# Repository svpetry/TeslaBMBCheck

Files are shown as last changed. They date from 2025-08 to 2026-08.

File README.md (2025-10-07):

# TeslaBMBCheck
Simple device that reads the voltage levels and temperatures from a Tesla Model S BMB board. It also supports balancing and clearing faults.

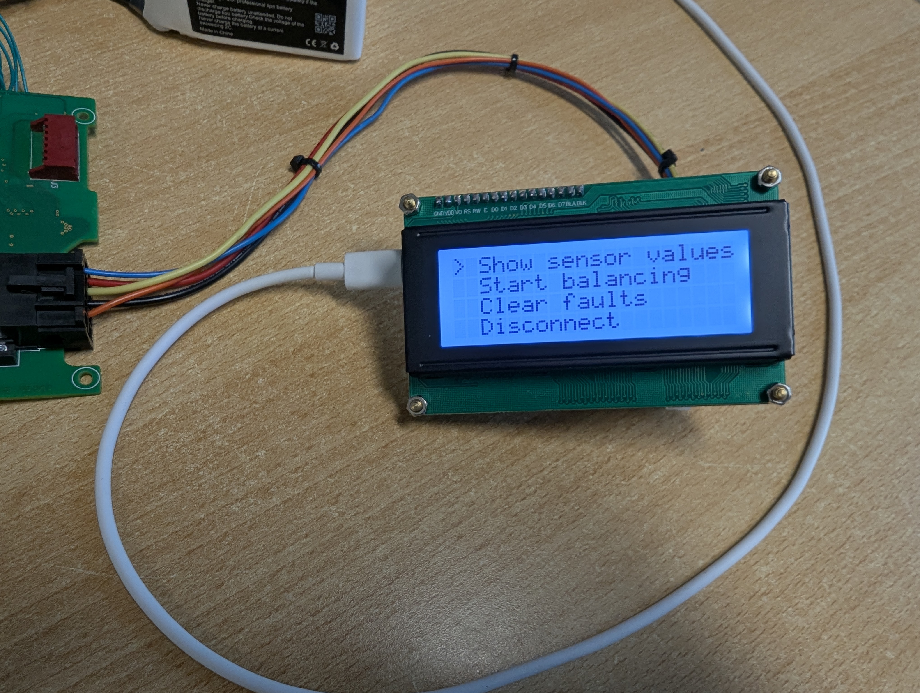
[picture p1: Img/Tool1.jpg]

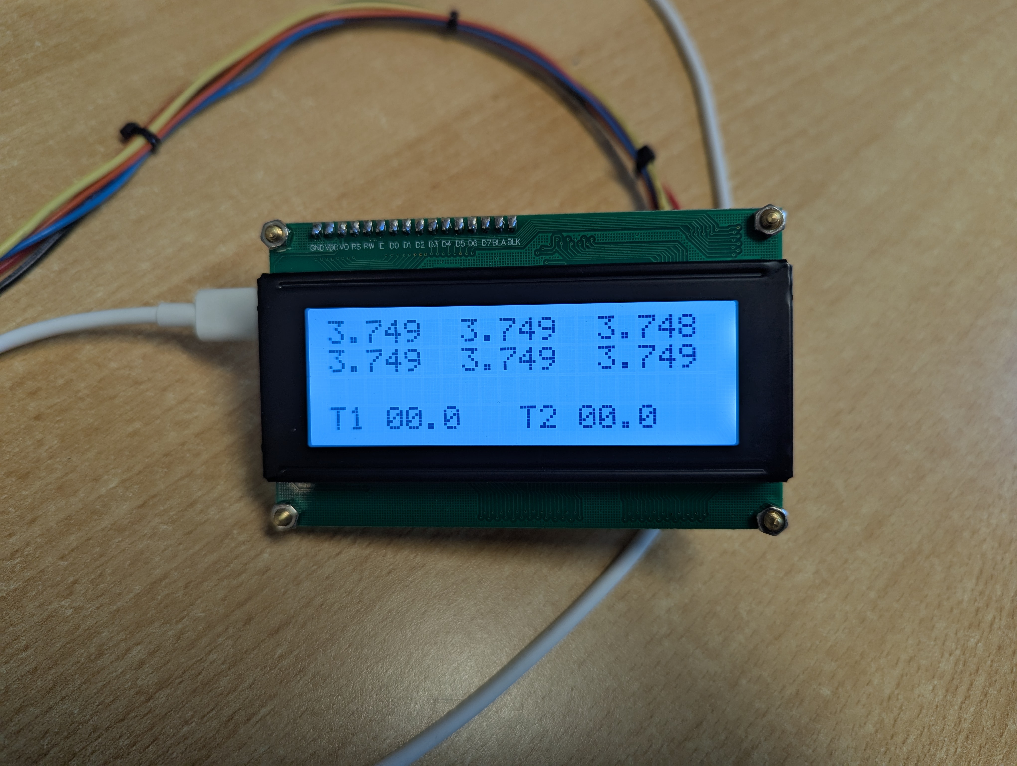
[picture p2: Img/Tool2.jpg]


## Module Locations

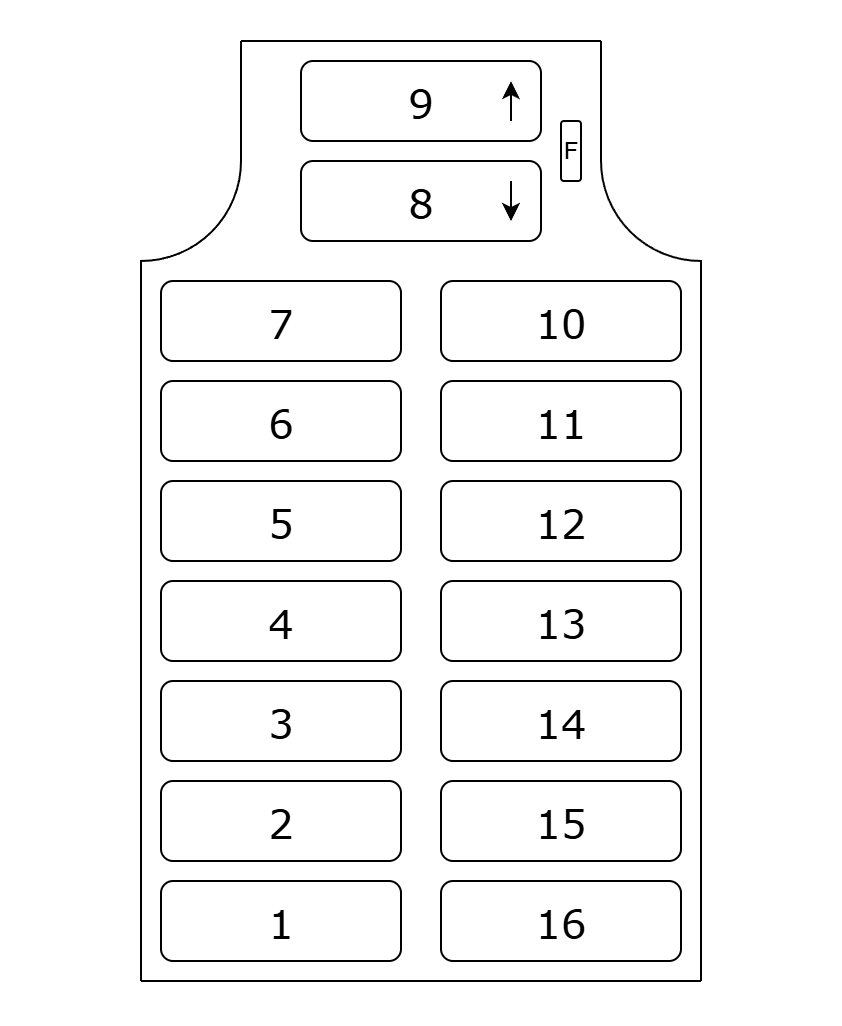
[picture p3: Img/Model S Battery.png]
Model S Battery Modules


## BMB Components

For each brick the BMB has a group of identical SMD components to read the voltage levels and do balancing. The elements in the topmost rectangle have already been replaced and re-sealed with epoxy.

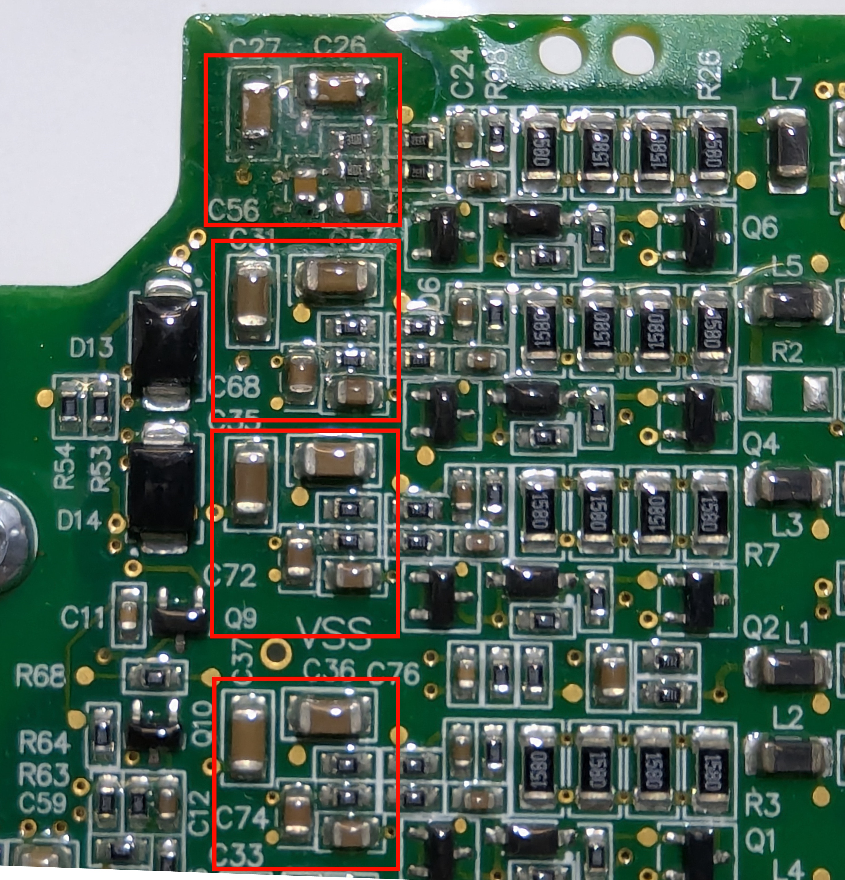
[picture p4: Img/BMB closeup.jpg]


## BMB Single Group For A Brick

The components here often have corrosion damage.

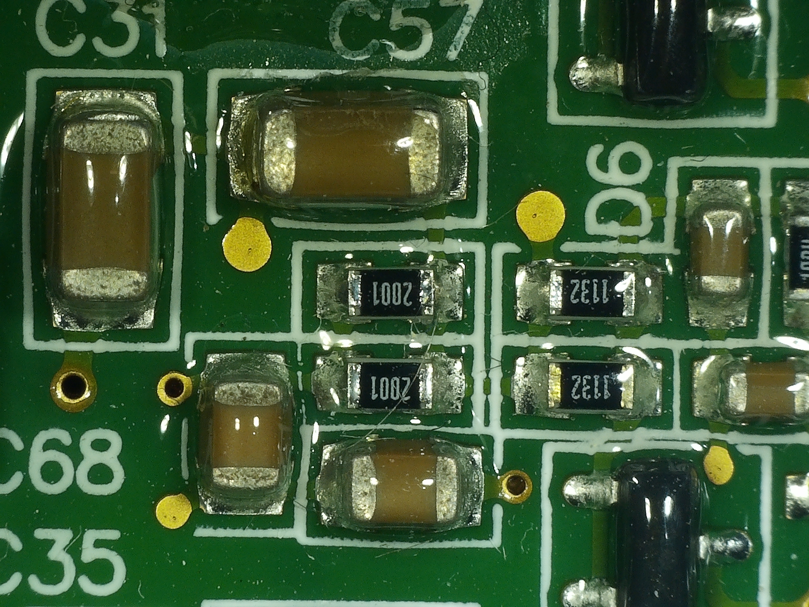
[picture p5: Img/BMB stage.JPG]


## BMB Resistor And Capacitor Values

These are the values I measured.

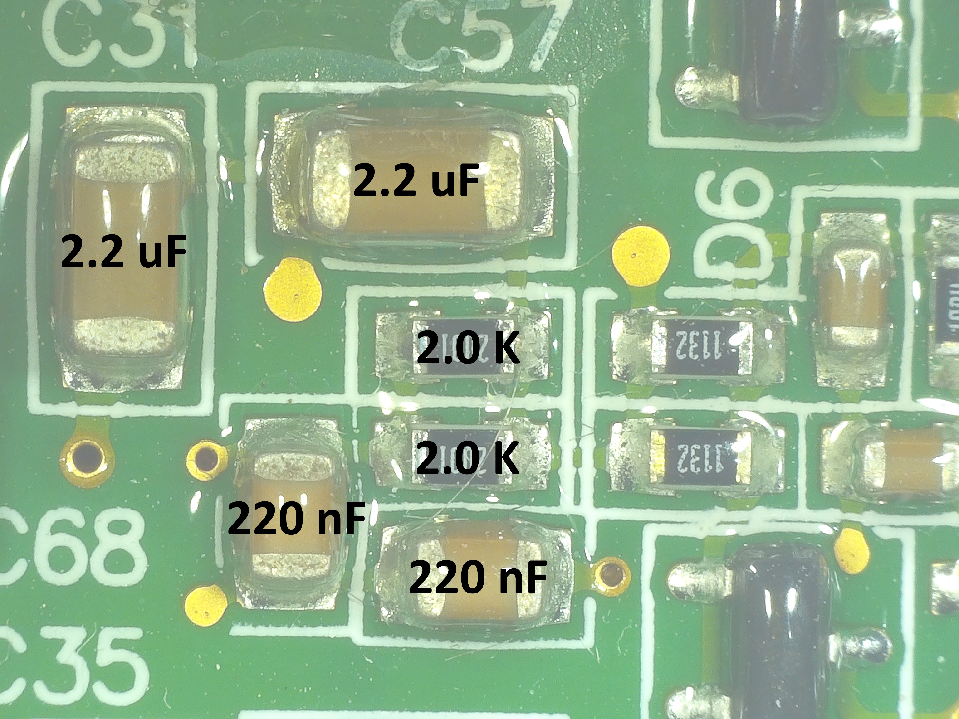
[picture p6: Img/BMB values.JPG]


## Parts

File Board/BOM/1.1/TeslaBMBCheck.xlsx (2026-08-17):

Name | Qty | Value
C1,C3,C4 | 3 | 100n
C2,C7 | 2 | 10u
C5 | 1 | 1u
C6 | 1 | 47n
C15,C17 | 2 | 22p
D2 | 1 | SS14
D15 | 1 | INFO
DS1 | 1 | WC1602A
J1 | 1 | TESLA_BMS
J2 | 1 | CHARGE
J9 | 1 | ICSP
K2 | 1 | SLA-05VDC-SL-C
Q1 | 1 | IRLML2244
Q2 | 1 | BSS138
Q3 | 1 | IRLML2502
R1,R2 | 2 | 5K1
R3,R4,R5 | 3 | 4K7
R6 | 1 | 15
R7,R8,R23 | 3 | 10K
R10 | 1 | 15K
R19 | 1 | 1K
RV1 | 1 | 10K
SW1,SW2 | 2
U1 | 1 | USBLC6
U2 | 1 | PIC18F2480-ISO
USB1 | 1 | POWER
Y1 | 1 | 10 MHz

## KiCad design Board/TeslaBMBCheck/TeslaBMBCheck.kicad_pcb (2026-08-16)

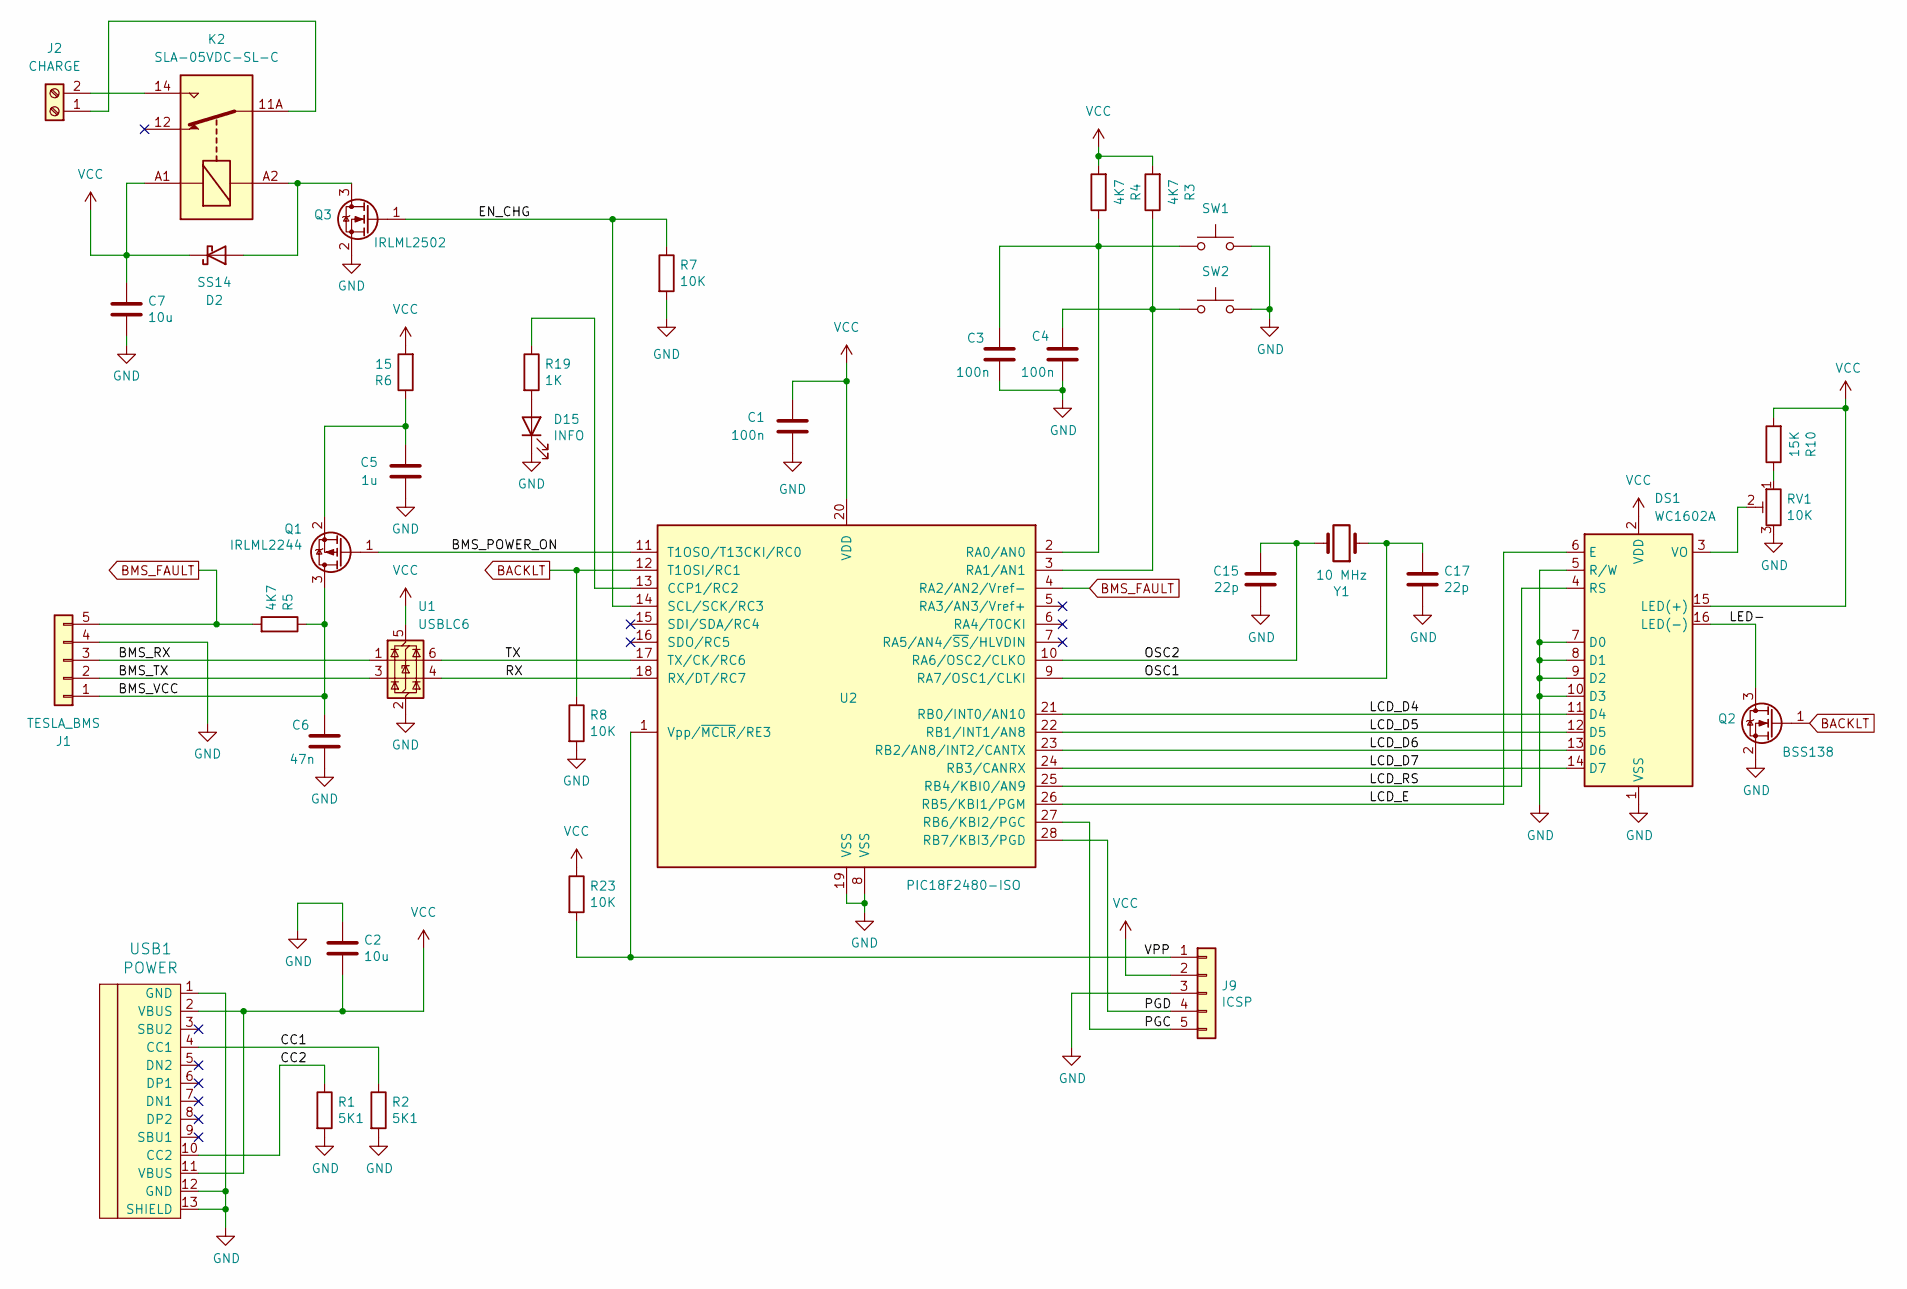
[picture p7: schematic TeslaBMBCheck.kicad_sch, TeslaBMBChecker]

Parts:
C1, C3, C4: 100n; C_0805_2012Metric
C2, C7: 10u; C_1206_3216Metric
C5: 1u; C_0805_2012Metric
C6: 47n; C_0805_2012Metric
C15, C17: 22p; C_0805_2012Metric
D2: SS14; D_SMA
D15: INFO; LED_0805_2012Metric
DS1: WC1602A; LCD-20x4
J1: TESLA_BMS; Molex_Mini-Fit_Jr_5566-10A_1x05_P4.20mm_Vertical
J2: CHARGE; KF7.62_2P
J9: ICSP; PinHeader_1x05_P2.54mm_Vertical
K2: SLA-05VDC-SL-C; Relay_SPDT_RAYEX-L90
Q1: IRLML2244; SOT-23
Q2: BSS138; SOT-23
Q3: IRLML2502; SOT-23
R1, R2: 5K1; R_0805_2012Metric
R3, R4, R5: 4K7; R_0805_2012Metric
R6: 15; R_0805_2012Metric
R7, R8, R23: 10K; R_0805_2012Metric
R10: 15K; R_0805_2012Metric
R19: 1K; R_0805_2012Metric
RV1: 10K; Potentiometer_Bourns_TC33X_Vertical
SW1, SW2: SW_SPST_CK_RS282G05A3
U1: USBLC6; SOT-23-6
U2: PIC18F2480-ISO; SOIC-28W_7.5x17.9mm_P1.27mm
USB1: POWER; HRO-TYPE-C-31-M-12
Y1: 10 MHz; Crystal_SMD_HC49-SD

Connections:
/BMS_POWER_ON: Q1.1 (G), U2.11 (T1OSO/T13CKI/RC0)
/BMS_RX: J1.3, U1.1 (I/O1)
/BMS_TX: J1.2, U1.3 (I/O2)
/BMS_VCC: C6.1, J1.1, Q1.3 (D), R5.1
/CC1: R2.1, USB1.4 (CC1)
/CC2: R1.1, USB1.10 (CC2)
/EN_CHG: Q3.1 (G), R7.1, U2.14 (SCL/SCK/RC3)
/LCD_D4: DS1.11 (D4), U2.21 (RB0/INT0/AN10)
/LCD_D5: DS1.12 (D5), U2.22 (RB1/INT1/AN8)
/LCD_D6: DS1.13 (D6), U2.23 (RB2/AN8/INT2/CANTX)
/LCD_D7: DS1.14 (D7), U2.24 (RB3/CANRX)
/LCD_E: DS1.6 (E), U2.26 (RB5/KBI1/PGM)
/LCD_RS: DS1.4 (RS), U2.25 (RB4/KBI0/AN9)
/LED-: DS1.16 (LED(-)), Q2.3 (D)
/OSC1: C17.1, U2.9 (RA7/OSC1/CLKI), Y1.1
/OSC2: C15.1, U2.10 (RA6/OSC2/CLKO), Y1.2
/PGC: J9.5, U2.27 (RB6/KBI2/PGC)
/PGD: J9.4, U2.28 (RB7/KBI3/PGD)
/RX: U1.4 (I/O2), U2.18 (RX/DT/RC7)
/TX: U1.6 (I/O1), U2.17 (TX/CK/RC6)
/VPP: J9.1, R23.2, U2.1 (Vpp/~MCLR/RE3)
BACKLT: Q2.1 (G), R8.1, U2.12 (T1OSI/RC1)
BMS_FAULT: J1.5, R5.2, U2.4 (RA2/AN2/Vref-)
GND: C1.2, C2.1, C3.2, C4.2, C5.2, C6.2, C7.2, C15.2, C17.2, D15.1 (K), DS1.1 (VSS), DS1.5 (R/W), DS1.7 (D0), DS1.8 (D1), DS1.9 (D2), DS1.10 (D3), J1.4, J9.3, Q2.2 (S), Q3.2 (S), R1.2, R2.2, R7.2, R8.2, RV1.3, SW1.2, SW2.2, U1.2 (GND), U2.8 (VSS), U2.19 (VSS), USB1.1 (GND), USB1.12 (GND), USB1.13 (SHIELD)
unnamed: D2.2 (A), K2.A2, Q3.3 (D)
unnamed: D15.2 (A), R19.2
unnamed: DS1.3 (VO), RV1.2
unnamed: J2.1, K2.11A, K2.11B
unnamed: J2.2, K2.14
unnamed: C5.1, Q1.2 (S), R6.1
unnamed: R10.1, RV1.1
unnamed: R19.1, U2.13 (CCP1/RC2)
unnamed: C3.1, R4.1, SW1.1, U2.2 (RA0/AN0)
unnamed: C4.1, R3.1, SW2.1, U2.3 (RA1/AN1)
VCC: C1.1, C2.2, C7.1, D2.1 (K), DS1.2 (VDD), DS1.15 (LED(+)), J9.2, K2.A1, R3.2, R4.2, R6.2, R10.2, R23.1, U1.5 (VBUS), U2.20 (VDD), USB1.2 (VBUS), USB1.11 (VBUS)

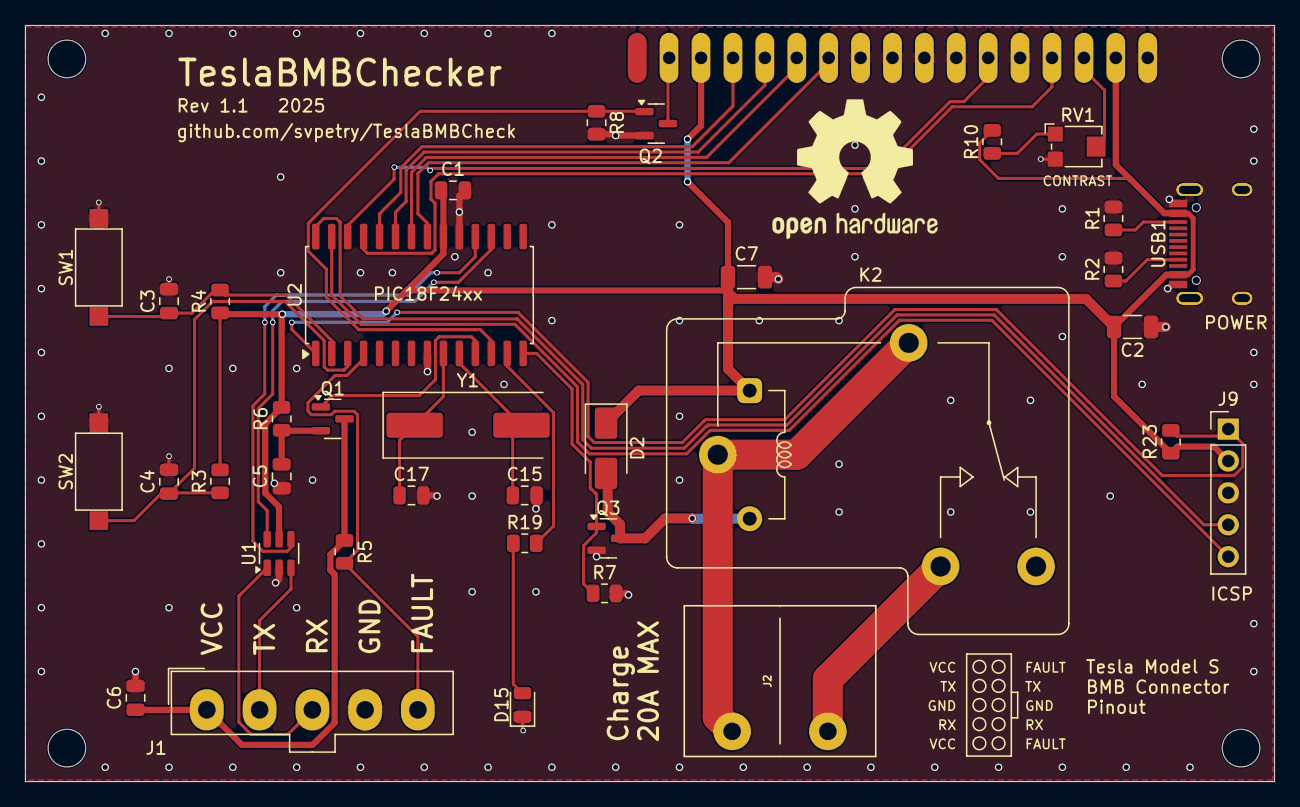
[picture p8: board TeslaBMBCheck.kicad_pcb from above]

Board: 2 copper layers, 99.4 x 60.2 mm, 37 parts (1 on the bottom side), 35 nets.

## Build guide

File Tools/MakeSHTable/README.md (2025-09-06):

This project is for generating the lookup table for the temperature calculation. I didn't want to include the float library into the PIC project, so everything is done with integer calculations.

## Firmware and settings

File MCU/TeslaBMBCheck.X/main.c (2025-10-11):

/*
 * File:   main.c
 * Author: svpet
 *
 * 
 * pin layout:
 * RA0: SW1 (0 = pressed)
 * RA1: SW2 (0 = pressed)
 * RA2: BMS_FAULT
 * RA3: -
 * RA4: -
 * RA5: -
 * RA6: OSC2
 * RA7: OSC1
 * RC0: BMS_POWER_ON (0 = active)
 * RC1: LCD backlight
 * RC2: Info LED
 * RC3: Charging relais
 * RC4: -
 * RC5: -
 * RC6: TX
 * RC7: RX
 * RE3: VPP (ICSP)
 * RB0: LCD_D4
 * RB1: LCD_D5
 * RB2: LCD_D6
 * RB3: LCD_D7
 * RB4: LCD_RS
 * RB5: LCD_E
 * RB6: PGC (ICSP)
 * RB7: PGD (ICSP)
 */

#include <xc.h>
#include <pic18f2480.h>
#include <string.h>
#include "config.h"
#include "base.h"
#include "lcd.h"
#include "uart.h"
#include "utils.h"
#include "bms-util.h"
#include "bms.h"
#include "board.h"
#include "types.h"

#define ENABLE_CHARGING 0

#define MODULE_ID 3
#define BMS_POWER_ON_DELAY 3000
#define BATT_SYMBOL_COUNT 4
#define VOLTAGE_CHECK_INTERVAL 5
#define CHARGE_CHECK_INTERVAL 60
#define MIN_CELL_VOLTAGE 2800
#define MAX_CELL_VOLTAGE 4175

bool connected = 0;

void Initialize(void) {
    TRISA = 0b11000111;
    LATA = 0;
    TRISB = 0b00000000;
    LATB = 0;
    TRISC = 0b10000000;
    LATC = 0b00000001;
    
    UART_Init(612500UL);

    __delay_ms(200);
    LcdInit();
}

void ConnectToBms(uint8_t module_id) {
    LcdClear();
    LcdPuts(4, 1, "Connecting...");
    
    connected = 0;
    
    SetBmsPower(1);
    __delay_ms(BMS_POWER_ON_DELAY);
    
    if (!ResetBoard()) {
        SetBmsPower(0);
        return;
    }
    if (!SetNewBoardId(module_id)) {
        SetBmsPower(0);
        return;
    }
    if (FindBoardId() != module_id) {
        SetBmsPower(0);
        return;
    }

    __delay_ms(100);
    ClearBmsFaults(MODULE_ID);

    connected = 1;
}

void DisconnectBms() {
    SetBmsPower(0);
    connected = 0;
    LcdClear();
    LcdPuts(4, 1, "Disconnected.");
    __delay_ms(1000);
}

void ShowBmsData(struct BmsData bms_data, bool show_temp) {
    char s[8];
    
    for (uint8_t cell = 0; cell < CELL_COUNT; cell++) {
        VoltageToStr(s, bms_data.v[cell], 0);
        LcdPuts((cell % 3) * 7, cell / 3, s);
    }
    
    if (show_temp) {
        for (uint8_t i = 0; i < 2; i++) {
            TempToStr(s, bms_data.t[i]);
            LcdPuts(3 + i * 10, 3, s);
        }
    } else {
        VoltageToStr(s, bms_data.mv, 1);
        LcdPuts(1, 3, s);
    }

    if (BmsFaultActive())
        LcdPuts(0, 2, "\x05\x06 Fault detected.");
    else
        LcdPuts(0, 2, "                    ");
}

void ShowStatus() {
    LcdClear();
    LcdPuts(0, 3, "T1");
    LcdPuts(10, 3, "T2");
    while (!GetBtnState(0) && !GetBtnState(1)) {
        struct BmsData data = ReadBmsData(MODULE_ID);
        ShowBmsData(data, 1);
        __delay_ms(1000);
    }
}

void ShowBatterySymbol(uint8_t cell, uint8_t counter, bool state) {
    uint8_t col = (cell % 3) * 7 + 5;
    uint8_t row = cell / 3;
    
    // Battery symbols are characters 1 (full), 2, 3 and 4 (empty)
    char battChar = 1 + counter;
    
    LcdPutChar(col, row, state ? battChar : ' ');
}

void EnableBalancers(bool balancers[CELL_COUNT]) {
    uint8_t bits = 0;
    for (int i = 0; i < CELL_COUNT; i++) {
        if (balancers[i])
            bits |= 1 << i;
    }
    EnableBmsBalancers(MODULE_ID, bits);
}

void Balance(uint16_t voltage) {
    LcdClear();

    bool balancers[CELL_COUNT];
    uint8_t batt_symbol = 0;
    
    char s[8];
    VoltageToStr(s, voltage, 0);
    LcdPuts(14, 3, s);
    
    struct BmsData data = ReadBmsData(MODULE_ID);
    ShowBmsData(data, 0);

    for (uint8_t cell = 0; cell < CELL_COUNT; cell++) {
        if (data.v[cell] > voltage) {
            ShowBatterySymbol(cell, batt_symbol, 1);
            balancers[cell] = 1;
        } else
            balancers[cell] = 0;
    }
    
    EnableBalancers(balancers);
    
    int seconds = 0;
    
    while (!GetBtnState(0) && !GetBtnState(1)) {
        if (seconds == VOLTAGE_CHECK_INTERVAL - 1) {
            EnableBmsBalancers(MODULE_ID, 0);
            __delay_ms(100);
            data = ReadBmsData(MODULE_ID);
            ShowBmsData(data, 0);
            EnableBalancers(balancers);
            __delay_ms(400);

            int count = 0;
            for (uint8_t cell = 0; cell < CELL_COUNT; cell++) {
                if (balancers[cell]) {
                    if (data.v[cell] <= voltage) {
                        balancers[cell] = 0;
                        ShowBatterySymbol(cell, batt_symbol, 0);
                    } else
                      count++;
                }
            }
            if (count == 0)
                LcdPuts(8, 3, "Done.");
            
            EnableBalancers(balancers);
        } else
            __delay_ms(500);
       
        for (uint8_t cell = 0; cell < CELL_COUNT; cell++) {
            if (balancers[cell])
                ShowBatterySymbol(cell, batt_symbol, 1);
        }
        batt_symbol = (batt_symbol + 1) % BATT_SYMBOL_COUNT;

        __delay_ms(500);

        for (uint8_t cell = 0; cell < CELL_COUNT; cell++) {
            if (balancers[cell])
                ShowBatterySymbol(cell, batt_symbol, 1);
        }
        batt_symbol = (batt_symbol + 1) % BATT_SYMBOL_COUNT;

        if (seconds == VOLTAGE_CHECK_INTERVAL - 1)
            seconds = 0;
        else
            seconds++;
    }
    EnableBmsBalancers(MODULE_ID, 0);

    LcdClear();
    WaitButtonsReleased();
}

void Charge(uint16_t voltage) {
    LcdClear();
    
    uint8_t batt_symbol = BATT_SYMBOL_COUNT - 1;

    char s[8];
    VoltageToStr(s, voltage, 0);
    LcdPuts(14, 3, s);

    struct BmsData data = ReadBmsData(MODULE_ID);
    ShowBmsData(data, 0);
    
    int seconds = 0;
    bool abort = 0;

    if (data.v_min < voltage) {
        while (!abort) {
            if (seconds % VOLTAGE_CHECK_INTERVAL == 0) {
                data = ReadBmsData(MODULE_ID);
                ShowBmsData(data, 0);
            }

            if (seconds == 0) {
                SetChargeRelais(0);
                __delay_ms(500);
                data = ReadBmsData(MODULE_ID);
                if (data.v_min > voltage)
                    break;
                SetChargeRelais(1);
            } else
                __delay_ms(500);
            
            for (uint8_t cell = 0; cell < CELL_COUNT; cell++)
                ShowBatterySymbol(cell, batt_symbol, 1);
            batt_symbol = (batt_symbol - 1) % BATT_SYMBOL_COUNT;
            
            __delay_ms(500);

            for (uint8_t cell = 0; cell < CELL_COUNT; cell++)
                ShowBatterySymbol(cell, batt_symbol, 1);
            batt_symbol = (batt_symbol - 1) % BATT_SYMBOL_COUNT;

            if (seconds == CHARGE_CHECK_INTERVAL - 1)
                seconds = 0;
            else
                seconds++;

            if (GetBtnState(0) || GetBtnState(1))
                abort = 1;
        }
        SetChargeRelais(0);
    }
    
    if (!abort)
        Balance(voltage);
    else {
        LcdClear();
        WaitButtonsReleased();
    }
}

uint16_t InputVoltage() {
    LcdClear();
    LcdPuts(2, 1, "Target voltage:");
    LcdPuts(3, 2, "3.700 V  Start");
    
    bool start = 0;
    int voltage = 0;
    char s[8];
    uint8_t pos = 0;
    char digits[4];
    
    digits[0] = 3;
    digits[1] = 7;
    digits[2] = 0;
    digits[3] = 0;
    
    do {
        WaitButtonsReleased();
        strcpy(s, "     ");
        if (pos < 5) {
            s[pos] = '^';
            LcdPuts(12, 3, "     ");
        } else 
            LcdPuts(12, 3, "^^^^^");
        LcdPuts(3, 3, s);
        
        uint8_t dpos = pos;
        if (dpos > 0) dpos--;

        while (!GetBtnState(0) && !start) {
            WaitForButtonPressed();
            if (GetBtnState(1)) {
                if (pos < 5) {
                    digits[dpos] = (digits[dpos] + 1) % 10;
                    s[0] = '0' + digits[dpos];
                    s[1] = 0;
                    LcdPuts(3 + pos, 2, s);
                } else {
                    start = 1;
                }
                WaitButtonsReleased();
            }
        }
        
        pos++;
        if (pos == 1)
            pos++;
        if (pos == 6)
            pos = 0;
    } while (!start);
    
    int factor = 1000;
    for (int i = 0; i < 4; i++) {
        voltage += digits[i] * factor;
        factor /= 10;
    }

    if (voltage > MAX_CELL_VOLTAGE)
        voltage = MAX_CELL_VOLTAGE;
    if (voltage < MIN_CELL_VOLTAGE)
        voltage = MIN_CELL_VOLTAGE;
    
    WaitButtonsReleased();
    return (uint16_t)voltage;
}

void ClearFaults() {
    LcdClear();
    WaitButtonsReleased();
    LcdPuts(1, 1, "Clearing faults...");
    __delay_ms(200);
    ClearBmsFaults(MODULE_ID);
    LcdPuts(7, 2, "Done.");
    WaitForButtonPressed();
}

void MainMenu() {
    while (1) {
        LcdClear();
        WaitButtonsReleased();
        
        if (!connected) {
            LcdPuts(0, 1, "Press SW2 to connect");
            LcdPuts(0, 3, "TeslaBMBChecker V1.1");
            while (!GetBtnState(1)) {
                SetLcdBacklight(0);
                __delay_ms(4);
                SetLcdBacklight(1);
                __delay_ms(1);
            }
            ConnectToBms(MODULE_ID);
            if (!connected) {
                LcdPuts(0, 1, "Connection failed.  ");
                WaitForButtonPressed();
            }
        } else {
            
            LcdPuts(0, 0, "> Show sensor values");
#if ENABLE_CHARGING
            LcdPuts(0, 1, "  Balance charge    ");
#else
            LcdPuts(0, 1, "  Balance           ");
#endif
            LcdPuts(0, 2, "  Clear faults      ");
            LcdPuts(0, 3, "  Disconnect        ");
            
            int menu_idx = 0;
            while (!GetBtnState(1)) {
                
                WaitButtonsReleased();

                bool fault = 0;
                while (!GetBtnState(0) && !GetBtnState(1)) {
                    if (BmsFaultActive() != fault) {
                        fault = BmsFaultActive();
                        if (fault)
                            LcdPuts(18, 3, "\x05\x06"); // Warning sign
                        else
                            LcdPuts(18, 3, "  ");
                    }
                }

                WaitForButtonPressed();
                
                if (GetBtnState(0)) {
                    menu_idx = (menu_idx + 1) % 4;

                    for (uint8_t i = 0; i < 4; i++) {
                        LcdPuts(0, i, menu_idx == i ? ">" : " ");
                    }
                }
            }
            
            LcdClear();
            WaitButtonsReleased();
            
            switch (menu_idx) {
                case 0: {
                    ShowStatus();
                    break;
                }
                case 1: {
                    uint16_t voltage = InputVoltage();
#if ENABLE_CHARGING
                    Charge(voltage);
#else
                    Balance(voltage);
#endif
                    break;
                }
                case 2: {
                    ClearFaults();
                    break;
                }
                case 3: {
                    DisconnectBms();
                    break;
                }
            }
        }
    }
}

void main(void) {
    Initialize();
    SetLcdBacklight(1);
    MainMenu();
}

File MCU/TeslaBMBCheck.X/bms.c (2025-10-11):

#include <pic18.h>
#include "base.h"

#include "uart.h"
#include "bms.h"
#include "bms-util.h"
#include "lcd.h"
#include "utils.h"

#define MAX_MODULE_ADDR 63
#define MAX_ATTEMPTS 5

// Lookup table for temperature calculation
static const uint16_t temp_table[1024] = {
    0, 0, 0, 0, 0, 0, 0, 0, 0, 0, 0, 0, 0, 0, 0, 0, 0, 0, 0, 0, 0, 0, 0, 0, 0, 0,
    0, 0, 0, 0, 0, 0, 0, 0, 0, 0, 0, 0, 0, 0, 0, 0, 0, 0, 0, 0, 0, 0, 0, 0, 0, 0,
    0, 0, 0, 0, 0, 0, 0, 0, 0, 0, 0, 0, 0, 0, 0, 0, 0, 0, 0, 0, 0, 0, 0, 0, 0, 0,
    0, 0, 0, 0, 0, 0, 0, 0, 0, 0, 0, 0, 0, 0, 0, 0, 0, 0, 0, 0, 0, 0, 0, 0, 0, 0,
    0, 0, 0, 0, 0, 0, 0, 0, 0, 0, 0, 0, 0, 0, 0, 0, 0, 0, 0, 0, 0, 0, 0, 0, 0, 0,
    0, 0, 0, 0, 0, 0, 0, 0, 0, 0, 0, 0, 0, 0, 0, 0, 0, 0, 0, 0, 0, 0, 0, 0, 0, 0,
    0, 0, 0, 0, 0, 0, 0, 0, 0, 0, 0, 0, 0, 0, 0, 0, 0, 0, 0, 0, 0, 0, 0, 0, 0, 0,
    0, 0, 0, 0, 0, 0, 0, 0, 0, 0, 0, 0, 0, 0, 0, 0, 0, 0, 0, 0, 0, 0, 0, 0, 0, 0,
    0, 0, 0, 0, 0, 0, 0, 0, 0, 0, 0, 0, 0, 0, 0, 0, 0, 0, 0, 0, 0, 0, 0, 0, 0, 0,
    0, 0, 0, 1, 2, 4, 5, 6, 7, 8, 9, 10, 11, 12, 13, 14, 15, 16, 17, 18, 19, 20,
    21, 22, 23, 25, 26, 27, 28, 29, 30, 31, 32, 33, 34, 35, 36, 37, 38, 39, 40,
    40, 41, 42, 43, 44, 45, 46, 47, 48, 49, 50, 51, 52, 53, 54, 55, 56, 57, 58,
    59, 60, 61, 61, 62, 63, 64, 65, 66, 67, 68, 69, 70, 71, 72, 73, 73, 74, 75,
    76, 77, 78, 79, 80, 81, 81, 82, 83, 84, 85, 86, 87, 88, 89, 89, 90, 91, 92,
    93, 94, 95, 95, 96, 97, 98, 99, 100, 101, 101, 102, 103, 104, 105, 106, 107,
    107, 108, 109, 110, 111, 112, 112, 113, 114, 115, 116, 117, 117, 118, 119,
    120, 121, 121, 122, 123, 124, 125, 126, 126, 127, 128, 129, 130, 130, 131,
    132, 133, 134, 134, 135, 136, 137, 138, 138, 139, 140, 141, 141, 142, 143,
    144, 145, 145, 146, 147, 148, 148, 149, 150, 151, 152, 152, 153, 154, 155,
    155, 156, 157, 158, 158, 159, 160, 161, 162, 162, 163, 164, 165, 165, 166,
    167, 168, 168, 169, 170, 171, 171, 172, 173, 173, 174, 175, 176, 176, 177,
    178, 179, 179, 180, 181, 182, 182, 183, 184, 185, 185, 186, 187, 187, 188,
    189, 190, 190, 191, 192, 192, 193, 194, 195, 195, 196, 197, 197, 198, 199,
    200, 200, 201, 202, 202, 203, 204, 205, 205, 206, 207, 207, 208, 209, 210,
    210, 211, 212, 212, 213, 214, 214, 215, 216, 216, 217, 218, 219, 219, 220,
    221, 221, 222, 223, 223, 224, 225, 225, 226, 227, 228, 228, 229, 230, 230,
    231, 232, 232, 233, 234, 234, 235, 236, 236, 237, 238, 238, 239, 240, 240,
    241, 242, 242, 243, 244, 244, 245, 246, 246, 247, 248, 248, 249, 250, 250,
    251, 252, 252, 253, 254, 254, 255, 256, 256, 257, 258, 258, 259, 260, 260,
    261, 262, 262, 263, 264, 264, 265, 266, 266, 267, 268, 268, 269, 270, 270,
    271, 271, 272, 273, 273, 274, 275, 275, 276, 277, 277, 278, 279, 279, 280,
    281, 281, 282, 282, 283, 284, 284, 285, 286, 286, 287, 288, 288, 289, 289,
    290, 291, 291, 292, 293, 293, 294, 295, 295, 296, 296, 297, 298, 298, 299,
    300, 300, 301, 302, 302, 303, 303, 304, 305, 305, 306, 307, 307, 308, 308,
    309, 310, 310, 311, 312, 312, 313, 313, 314, 315, 315, 316, 317, 317, 318,
    318, 319, 320, 320, 321, 322, 322, 323, 323, 324, 325, 325, 326, 327, 327,
    328, 328, 329, 330, 330, 331, 331, 332, 333, 333, 334, 335, 335, 336, 336,
    337, 338, 338, 339, 339, 340, 341, 341, 342, 343, 343, 344, 344, 345, 346,
    346, 347, 347, 348, 349, 349, 350, 350, 351, 352, 352, 353, 354, 354, 355,
    355, 356, 357, 357, 358, 358, 359, 360, 360, 361, 361, 362, 363, 363, 364,
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
};

uint8_t FindBoardId() {
    uint8_t payload[3];
    uint8_t buff[8];

    payload[0] = 0;
    payload[1] = 0; // read registers starting at 0
    payload[2] = 1; // read one byte
    for (uint8_t x = 1; x <= MAX_MODULE_ADDR; x++) {
        payload[0] = (uint8_t)(x << 1);
        BMS_SendData(payload, 3, 0);
        BMS_ShortDelay();
        BMS_ShortDelay();
        if (BMS_GetReply(buff, 8) > 4) {
            if (buff[0] == (x << 1) && buff[1] == 0 && buff[2] == 1 && buff[4] > 0)
                return x;
        }
        BMS_ShortDelay();
    }
    
    return 0;
}

bool ResetBoard() {
    uint8_t payload[3];
    uint8_t buff[8];
    
    for (int i = 0; i < 8; i++) {
        buff[i] = 0;
    }

    for (int attempts = 0; attempts < MAX_ATTEMPTS; attempts++) {
        payload[0] = 0x3F << 1; // broadcast the reset command
        payload[1] = REG_RESET; // reset
        payload[2] = RESET_MAGIC_CODE; // data to cause a reset
        
        BMS_SendData(payload, 3, 1);
        BMS_LongDelay();
        BMS_GetReply(buff, 8);
        if (buff[0] == 0x7F && buff[1] == 0x3C && buff[2] == 0xA5 && buff[3] == 0x57) return 1;
       
        BMS_LongDelay();
    }
    return 0;
}

bool SetNewBoardId(uint8_t id) {
    uint8_t payload[3];
    uint8_t buff[10];
    int retLen;

    payload[0] = 0;
    payload[1] = 0;
    payload[2] = 1;

    retLen = BMS_SendDataWithReply(payload, 3, 0, buff, 4);
    if (retLen == 4) {
        if (buff[0] == 0x80 && buff[1] == 0 && buff[2] == 1) {
            payload[0] = 0;
            payload[1] = REG_ADDR_CTRL;
            payload[2] = id | 0x80;
            BMS_SendData(payload, 3, 1);
            BMS_LongDelay();
            if (BMS_GetReply(buff, 10) > 2) {
                if (buff[0] == (0x81) && buff[1] == REG_ADDR_CTRL && buff[2] == (id + 0x80))
                    return 1;
            }
        }
    }
    return 0;
}

/*
 * Old method with Steinhart-Hart formula.
 * 
static uint16_t CalcTemp(uint8_t buff[], int index) {
    float tempCalc;
    float tempTemp;

    tempTemp = (1.78f / ((buff[index] * 256 + buff[index + 1] + 2) / 33046.0f) - 3.57f);
    tempTemp *= 1000.0f;
    tempCalc =  (float)(1.0f / (0.0007610373573f + (0.0002728524832 * logf(tempTemp)) + (powf(logf(tempTemp), 3) * 0.0000001022822735f)));
    tempCalc = tempCalc - 273.15f;
    if (tempCalc < 0) tempCalc = 0;
    if (tempCalc > 99) tempCalc = 99;
    return (uint16_t)(tempCalc * 10.0f);
}
*/

static uint16_t CalcTemp(uint8_t buff[], int index) {
    uint16_t value = buff[index] * 256 + buff[index + 1];
    uint16_t table_idx = value >> 3;
    if (table_idx > 1022)
        return 999;
    
    // interpolation (not really necessary...)
    uint16_t v1 = temp_table[table_idx];
    uint16_t v2 = temp_table[table_idx + 1];
    return v1 + (((v2 - v1) * (value & 0x07)) >> 3);
}
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

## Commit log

2025-07-05 Initial commit (WIP)
    [TeslaBMBCheck.kicad_pcb, TeslaBMBCheck.kicad_sch]
2025-07-10 Board & schematic
    [TeslaBMBCheck.kicad_pcb, TeslaBMBCheck.kicad_sch]
2025-07-10 Change info LED connection
    [TeslaBMBCheck.kicad_pcb, TeslaBMBCheck.kicad_sch]
2025-07-11 Layout improvements
    [TeslaBMBCheck.kicad_pcb, TeslaBMBCheck.kicad_sch]
2025-07-11 Migration to PIC18F2480. Replaces float with integer calculations. Use lookup table for temperature values.
    [bms.c, main.c, uart.c]
2025-07-11 Final fixes. Created Gerber files.
    [TeslaBMBCheck-B_Cu.gbl, TeslaBMBCheck-B_Mask.gbs, TeslaBMBCheck-B_Paste.gbp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]
2025-07-14 Replaces float with integer calculcations.
    [bms.c]
2025-07-26 Fixes swapped RX/TX. Changes R10 value
    [TeslaBMBCheck.kicad_pcb, TeslaBMBCheck.kicad_sch]
2025-07-27 Adds fault detection and clearing.
    [TeslaBMBCheck.kicad_pcb, TeslaBMBCheck.kicad_sch]
2025-07-27 Refactoring. Adds battery symbols. Adds warning sign for faults.
2025-08-16 Small fixes. Remove KiCad warnings.
    [TeslaBMBCheck.kicad_sch]
2025-08-30 Minor fixes. Clear faults on connect.
    [main.c]
2025-09-25 Minor improvements
    [TeslaBMBCheck.kicad_pcb, TeslaBMBCheck.kicad_sch]
2025-09-26 Adds charging relais. New layout.
    [TeslaBMBCheck.kicad_pcb, TeslaBMBCheck.kicad_sch]
2025-09-26 Minor layout changes
    [TeslaBMBCheck.kicad_pcb]
2025-09-26 Adds 1.1 gerber files.
    [TeslaBMBCheck-B_Cu.gbl, TeslaBMBCheck-B_Mask.gbs, TeslaBMBCheck-B_Paste.gbp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]
2025-10-11 Implemented charging mode
2025-10-11 Fixed charging. Change firmware revision to 1.1
    [main.c]
2026-08-16 Migrate to KiCad 10. Add 1.1 BOM
    [TeslaBMBCheck.kicad_pcb, TeslaBMBCheck.kicad_sch, TeslaBMBCheck.xlsx]
2026-08-17 fix BOM
    [TeslaBMBCheck.xlsx]
2026-10-12 Charging mode improvements.
2026-10-23 Improved button reaction.
2026-10-23 Remember balance target voltages in EEPROM
2026-10-23 Balance cells above target voltage while charging
2026-10-23 Restart charging when cell voltages drop after balancing
